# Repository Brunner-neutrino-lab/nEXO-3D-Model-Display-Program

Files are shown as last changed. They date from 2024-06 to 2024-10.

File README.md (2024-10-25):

# nEXO 3D Model and Display

## Overview

This project showcases a scaled-down, 3D-printed model of the nEXO detector, designed to visualize various data related to muon interactions and double beta decay events. The model is created using SolidWorks and powered by a Raspberry Pi, enabling interactive LED displays and simulated data visualization. This project aims to present condensed data from ten years of observation, highlighting the rarity of neutrino-less double beta decay.

## Table of Contents

1. [Introduction](#introduction)
2. [Project Features](#project-features)
3. [Responsibilities](#responsibilities)
4. [Hardware Components](#hardware-components)
5. [Software Components](#software-components)
6. [Setup and Installation](#setup-and-installation)
7. [Data Simulation](#data-simulation)
8. [Usage](#usage)
9. [Acknowledgments](#acknowledgments)

## Introduction

The nEXO detector is part of an experiment projected to detect neutrino-less double beta decay. Our project involves creating a scaled-down 3D model of the detector to visualize simulated muon data and rare decay events in an engaging and informative manner.

## Project Features

- **True-to-Scale 3D Model**: Created in SolidWorks, scaled down by a factor of 100, and optimized for 3D printing.
- **Simulated Data Visualization**:
  - Muons passing through the TPC (Time Projection Chamber).
  - Muons passing through the outer detector.
  - Coincident muons passing through both the TPC and outer detector.
  - Background Region of Interest (ROI) data.
  - Xenon 137 data.
  - Estimated rate of neutrino-less double beta decay.
- **Interactive LED Display**: Powered by a Raspberry Pi, the LED display will showcase multiple half-lives of the decay to highlight its rarity.
- **Condensed Time Frame**: Displaying ten years or five years of data in a two-minute or one-minute visualization respectively.

## Responsibilities

1. 3D model and printing
- Grace, Felix
2. Hardware
- Julien, Felix 
3. Programming
- Sophie, Emilio, Eliot

Brian is advising the programming and hardware

## Hardware Components

- Raspberry Pi (User: pi,  Pass: Element54$)
- 3D-printed model of the nEXO detector (32 components)
- LEDs (5 blue for walls and 4 blue for floor, RGB for TPC)
- Power supply
- Current-limiting resistors
- IC (transistors)
- HAT for raspberry pi
- Wires (mainly used 26AWG)
- Glue
- Mirror sheet

## Software Components

- SolidWorks for 3D modeling
- Python for controlling the Raspberry Pi and LEDs
- Data from previous simulation scripts for muon and decay events

## Setup and Installation

1. **3D Printing**:
   - Use the SolidWorks files provided in the [sharepoint](https://mcgill.sharepoint.com/:f:/s/BrunnerNeutrinoLabModels_Group/EvGFXZofQUZPt6qD_oMlr6YBIfcuM76ZlL9AQwnTyHu-Tg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) to print the scaled-down model of the nEXO detector.
   
2. **Hardware Assembly**:
   - Schematics for the Raspberry Pi HAT and inside the model are found in the 'Schematics' folder.
   - Full tutorial on how to asssemble your own HAT found in 'nEXO Scale Model HAT text.docx'

4. **Software Installation**:
  - Assignment of GPIO pins for LEDS:
      - wallGPIO = 17 #physical/board pin 11
      - floorGPIO = 27 #physical/board pin 13
      - redGPIO = 9 #physical/board pin 21
      - greenGPIO = 11 #physical/board pin 23
      - blueGPIO = 25 #physical/board pin 22
  - The program to display the LEDs is found in the file 'LED_program.py'
  - 'Test.py' was only used to store the RGB values for the TPC colours.
      - in the 'Schematic' folder the LED colour assignment to events is found.

## Data Simulation
General approach: calculate the mean/expected time between events (for our time scale of 2 min = 10 years), then randomly sample the time between LED flashes using an exponential distribution (distribution for time between Poisson events). We have the option
 to vary the half-life of 0vbb as well as the LXe volume (inner 2t or inner 1t). 

The TPC will be flashed different colours for 5 different events in the ROI (the ROI is SS events, with energy within 0vbb FHWM): 
  - 0vbb
  - 2vbb
  - solar v
  - Xe-137 activations
  - and the remaining background events. 

0vbb: Mean number of decays per year is calculated based on the mean lifetime (half-life divided by log(2)), assuming 76.1% of events are in the ROI (as FHWM is approximately 76.1% of area under Gaussian distribution). 

  - 3 sigma discovery potential half-life: 7.4 x 10^27 years (https://iopscience.iop.org/article/10.1088/1361-6471/ac3631/pdf)   
  - Half-life sensitivity: 1.35 × 10^28 years
  - Our third option is currently 1 x 10^27 years.

Total background rate (https://arxiv.org/abs/1805.11142v2, table 3.1):  
  - Inner 2 tons: 3.6 × 10^−4 events/(FWHM·kg·yr)  
  - Inner 1 ton: 1.4 × 10^−4 events/(FWHM·kg·yr)  

Events in the background are separated into 2vbb, solar v, Xe-137 and remaining background according to the composition within FWHM for the inner 2t (https://iopscience.iop.org/article/10.1088/1361-6471/ac3631/pdf, estimated from Fig. 8):  
  - 2vbb: 0.8%  
  - Solar v: 2.1%  
  - Xe-137: 2.4%   
  - Rest of background: 94.7%  

The outer detector (walls and floor) will be flashed for muons (these rates may have to be scaled differently as they are very high with our time scale; currently the lights just stay on):  
  - Muons through TPC: about 0.6 per day 
  - Muons through outer cryostat: about 5 per day 

## Usage

1. **Start the Visualization**:
   - Run the main control script: GUI_program_with_LEDs.py
   - GUI will allow the user to choose options before running simulation

2. **Interacting with the Model**:
   - The LEDs will display different data sets including muons, 2vbb, 0vbb, ROI background data, and Xenon 137 data.
   - There will be an option to view the data from the inner 1 tonne as well as the inner 2 tonne of the detector.
   - Observe the visualization of the estimated rate of neutrino-less double beta decay and its half-lives.
3. **Connecting over SSH**
   - pi must be connected to the same network as device (ethernet/internet)
   - type into terminal 'ssh pi@[pi IP address]'
   - if displaying on touchscreeen you have to define the display enviroment (the screen is just DISPLAY=:0) before the command
     - ex. DISPLAY=:0 gui.py
     - ex. sudo DISPLAY=:0 LEDs.py

## Acknowledgments

This project is developed for the nEXO collaboration's Director's Review.
For questions contact Grace at grace.champagne@mail.mcgill.ca

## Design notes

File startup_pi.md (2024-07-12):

## How to start the pi!

1. Make sure the VGA cable is connectly to the model and the pi
2. Plug in the power supply the the female connector on the pi box
3. The program should startup at boot and now is ready to simulate!
* (the first simulation may not turn on LEDs, just wait for the timer to count down then start again)
* Also the command window can be dragged around screen

## To shut down

1. Press the RaspberryPi symbol in the top left corner and select logout
2. A window should pop up, select shutdown
3. Wait for the green light to fully shut off then unplug (this protects the SD card)

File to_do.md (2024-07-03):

# To Do List

### 3D Modeling

| Task | Person/Area | Deadline | Status | Notes|
|---|---|---|---|---|
| water tank and platform body | Grace |  |✅ Completed  |need to clean up stringing in truss a bit|
|  cryostat | Grace |  |✅ Completed | need to update  |
| platform roof and tank roof| Sophie |  | ✅ Completed | |
| gantry and stairs on roof | Sophie | | ✅ Completed |  |
| cryopit | Julien| | ✅ Completed | going to remodel with the 3D scans of the pit |
| cave and cryopit base | Felix | | ✅ Completed | |
| added connections between different pieces and channels through walls and in base for wiring | Felix | | ✅ Completed |  |
| added channels in floor and access from bottom of base and added ladders to platform| Grace| | ✅ Completed |  |
| new cryostat | | June 28, 2024  |✅ Completed | only need to change supporting structure not TPC or spheres|
| cages for ladders | | | ⬜️ Incomplete | should try with soluable filament |
| rpi case | Felix  |  |✅ Completed | added a VGA connector hole, added room for HAT, need to add screw terminals to connect screw in distribution terminal onto roof |
| cryopit bottom | | |✅ Completed  | make hole larger to fit screw in terminal and re add hole for platform body and added a way to remove terminal and fixed more things |

### Prints (for first model)

| Task | Deadline | Status | Print Time| Notes|
|---|---|---|---|---|
| tank body | | ✅ Completed | 14h|  |
| tank roof and floor |  | ✅ Completed | 3h |  |
| cryostat frame | |✅ Completed | 1h | got to print with no stringing (slower speed + dried filament |
| TPC cover |  |✅ Completed  | 15 min | |
| TPC | |  ✅ Completed | | |
| platform and walkway | | ✅ Completed | 6h| glued on walkway|
| platform roof | | ✅ Completed | 2h |  |
| ladders | June 28, 2024 | ✅ Completed  |  30min | slow down the print speed and decrease layer thickness |
| ladder cages | June 28, 2024 | ⬜️ Incomplete |  | try with soluable |
| gantry crane and boxes | | ✅ Completed | 1h |  |
| cave body | June 26, 2024 |✅ Completed  |  24h | |
| cave dome | June 28, 2024 | ✅ Completed | 14h  | |
| cryopit base | June 28, 2024 | ✅ Completed|  15h| the bottom didn't print correctly may have to reprint |
| cryostat shells | June 26, 2024 | ✅ Completed| 1h  | |
| cryostat supports |  June 28, 2024 | 🔄 In Progress | | for some reason not printing well even though have printed before |
| rpi case | June 28, 2024  |✅ Completed| | |

### Hardware and Software

| Task | Person/Area | Deadline | Status | Notes |
|---|---|---|---|---|
| make plan for videos | Grace + Hannah |  | ✅ Completed  | |
| filming video | Grace + Hannah | June 26, 2024 | 🔄 In Progress | |
| make schematic for HAT |Julien, Grace |  | ✅ Completed | |
| test LEDs with pi | Sophie, Julien | | ✅ Completed | |
| design HAT |  Julien | June 28, 2024 | ✅ Completed | |
| solder first HAT | | June 28, 2024 | ✅ Completed  | |
| test HAT | | |  ✅ Completed | works! however, VGA cable has connected pins so looking for new cable|
| write test code for LEDs | Sophie |  |  ✅ Completed | |
| sand down tank interier and glue reflective foil | Grace | July 4, 2024 |  ✅ Completed |  |
| write GUI for touchscreen | Emilio + Eliot | June 28, 2024 | 🔄 In Progress | try to include option to play video |
| glue screw in terminal onto cryopit base panel |  |  |⬜️ Incomplete |  |
| glue wires and LEDs into place |  |  |  ✅ Completed |  |
| test GUI | |  | ⬜️ Incomplete|  |
| test entire code |  |  | ⬜️ Incomplete |  |

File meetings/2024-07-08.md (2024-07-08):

# Meeting 3

### LIGHTS ON MODEL WORK!

## 3D Model
- all prints completed except one roof tile
- half of the model glued in
- all wiring glued in

### Next steps
- finish final print
- continue gluing rest of model
- secure in screw terminal
- print and assemble 2 more models
  - may need some extra help
- add final items to procurement
- make small beam

## Software
- program completed

### Next steps
- test touchscreen program on pi
- comments on touchscreen screen

## Hardware
- 2/4 HATs completed

### Next steps
- continue third and fourth HAT

## Plan for Video
- almost everything filmed: just need to film final model working

## To Do
- send pics and videos

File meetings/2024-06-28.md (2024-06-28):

# Meeting 3

## 3D Model
- outer cave printed
- printing dome
- added cap to put in the screw terminal for VGA cable
- case for raspberry pi printed
- glued all LEDs into windows and wires on wall and floor
- glued platform and plates together
- paint the lights

### Next steps
- glueing reflective coating
- printing cryostat
- tpc today, tpc cover
- print extra rectangle
- extra pieces: just in case pieces break

## Software
- sophie wrote test code to choose LED colours and for LEDs to flash
- eliot wrote code to add halflives ad the inner 1t and 2t
- issue: when switching between halflives and which volume you want it causes issues due to while true loop
  - maybe add time limit or just stop code
- added GUI to display the colour assignments and options to toggle half lives and volume
- look into displaying a video
- look into other time scales for the muons

### Next steps
- add to git

## Hardware
- soldered 2/3 HATs (tested and circuit works!)
- issue: VGA cable is not 1 to 1

### Next steps
- either make a new VGA cable or order a custom 1 to 1 cable

## Plan for Video
- filming today!!!
- quick explanation of what nEXO is and showcasing the model
- filming group members doing different tasks
- sub teams should write a script saying quick overview of what you did and how it contributes to the model
  - add in the scientific importance
- tentative deadline to film: July 9

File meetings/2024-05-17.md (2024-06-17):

# nEXO Model Meeting 2

### Updates:
**3D model:**
- Completed
  - Connections implemented between components
  - Channels created for LED wiring
  - Added walkway supports around platform structure
  - Printed a prototype base - tank and floor of tank fit in almost perfectly
  - added channels up the walls for LED wires
- In progress
  - modelling the cave in solidworks
  - prints - have printed cryostat (minus clear TPC), tank floor, outer platform body
- Next steps
  - print water tank, tank floor, cave, cryostat frame, roof, walkway

**Hardware:**
- Completed
  - Decided on LEDs - same colour for walls and floor [https://www.digikey.com/en/products/detail/adafruit-industries-llc/5490/16630594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]
- In progress
  - Designing the HAT - rough plan completed
  - Screenshot 2024-06-16 at 3 19 56 PM
  - calculting resistor values for LEDs
     - wall and floor LEDs will have same value

- Next steps
  - Printing HAT and soldering components
  - Testing LEDs with Pi - we only tested them with the 3.3V pin
 
**Program:**
- Completed
  - Assigned pins to LEDs (See README.md)
- In Progress
  - have looked at event rates, some events like muons are very common whereas others like Xe 137 are very very rare
  - we will test these real times and if they are not great we will see
  - writing code for rpi to control LEDs
- Next steps
  - writing PWM program to control the intensity of light and change colours in RGB
  - send out email with event rates to circulate for comments

### Discussion:
- going to use VGA 15 pin connector now instead of bulky d sub
- making prototype of circuit

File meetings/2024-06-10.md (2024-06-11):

# First nEXO 3D model meeting:

### Plan: create a mini model of nExo that can be printed
includes water tank, platform, cryopit, cyostat
LED in walls and in TPC that flash with expected rates of data
almost all solidworks files have been completed
water tank printed in shiny filament for stainless steel
bought soluble filament to print platform with, some troubleshooting with the soluble
blue liht in outer detector when muon passes - only coincident event
TPC red for bg event
green for 2nbb
purple for 0nbb assuming 7.4x10^27 year half life

### Next steps:
- connections bw pieces to fit in each other
- testing soluble filament
- add holes for wiring
- test id small pcb is needed, wiring plan
- acquire and simulate data, put it into a ras pi
- aim to have the project finished by the first week of july

### Questions:
- how much real time should correspond to a day of nEXO data taking??? (2min??)
- other events we want to show?
- use SLAC git for ras pi programming
- show a version with increased rates of 0nbb since it is low
- could have a function switch with an interactive touch screen to change the probablities

## Discussion:
#### Notes:
- updated CAD bc skirt is out of nickel now (no longer electro form copper) (verify with who?) - verified
- Brian might take more of an advisory role for ras pi programming
- for multi-colour LED, might want to find other LEDs, soldering 4 wires to the SMDs might be tough
- circuit can be external, the LEDs will require a driver
- probably need a pcb to deal with all the LEDs
- make a SLAC in nEXO,
- first look at how soldering to the LEDs go, Brian will look at other LEDs
- Look-up table easy, less fun, might be interesting to go with a RNG
- Looking for a generic hat, might not need a custom pcb
#### Roles:
- Sophie will take lead with programming the pi, with Emilio, Kavin to help
- Tania and Felix will check the LEDs and work with the hardware
- Julien will look into the circuit design on kicad and build/look for the hat/pcb
- Grace and felix will continue with the CAD files
- Eliot help with printing
#### To do:
- Use McGill's git, invite Brian
- Regan and Soud offered to help getting the data
- Looking to keep this meeting time

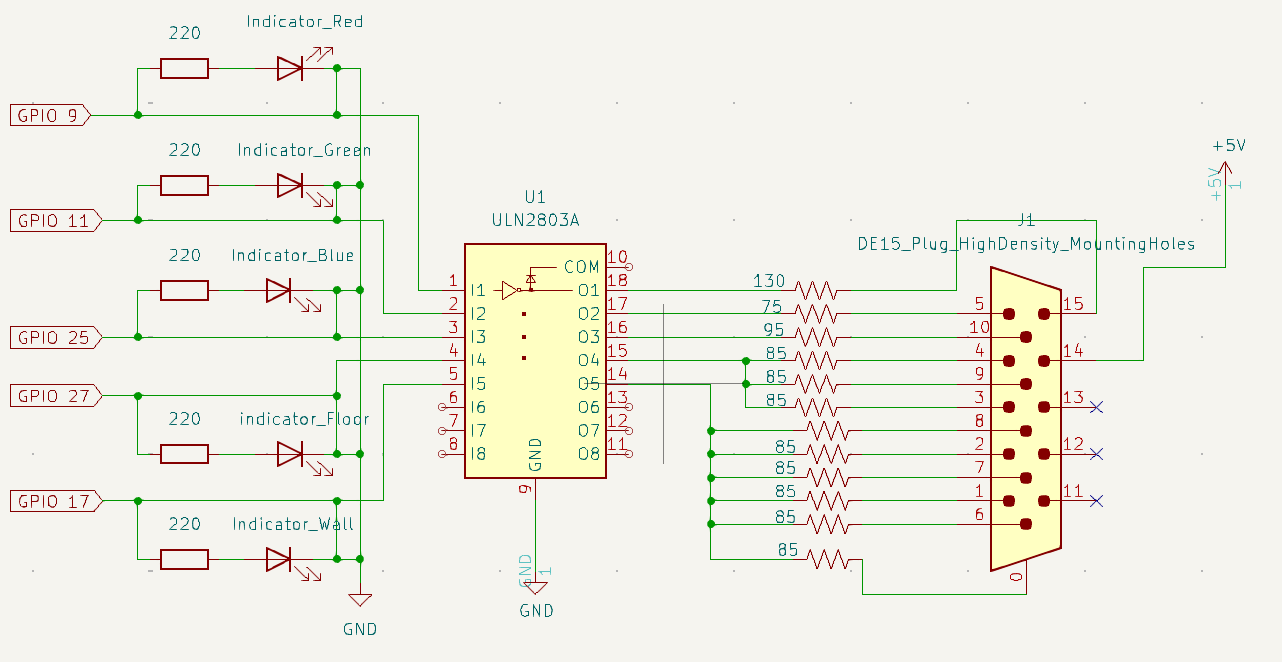
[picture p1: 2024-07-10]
kicad schematic/HAT circuit.png

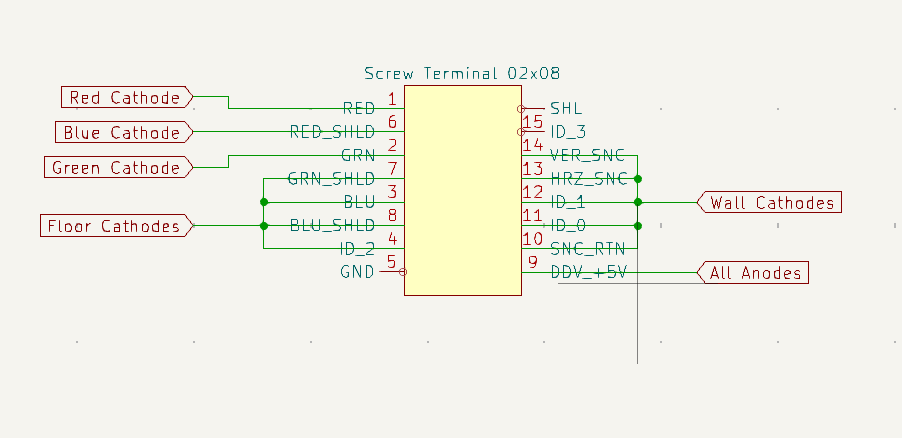
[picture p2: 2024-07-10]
kicad schematic/Screw terminal pinout.png

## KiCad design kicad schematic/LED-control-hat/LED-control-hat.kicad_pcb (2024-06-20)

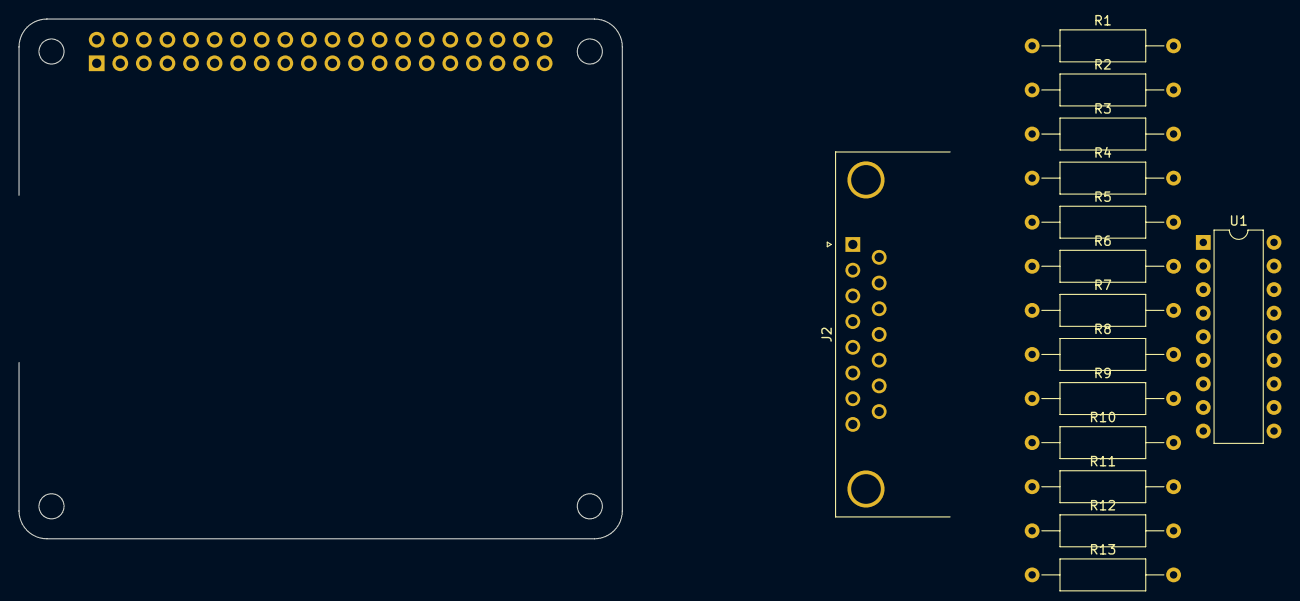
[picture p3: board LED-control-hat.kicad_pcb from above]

Board: 2 copper layers, 65.0 x 56.0 mm, 20 parts (1 on the bottom side), 26 nets, no tracks yet.

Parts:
J1: GPIO; PinSocket_2x20_P2.54mm_Vertical
J2: DA15_Receptacle; DSUB-15_Female_Horizontal_P2.77x2.84mm_EdgePinOffset7.70mm_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
MH1, MH2, MH3, MH4: MountingHole_2.7mm_M2.5
R1, R2, R3, R4, R5, R6, R7, R8, R9, R10, R11, R12, R13: R_US; R_Axial_DIN0309_L9.0mm_D3.2mm_P15.24mm_Horizontal
U1: ULN2803A; DIP-18_W7.62mm

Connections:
+3V3: J1.1, J1.17
+5V: J1.2, J1.4, J2.1
/GPIO17: J1.11, U1.1 (I1)
/GPIO22: J1.15, U1.2 (I2)
/GPIO23: J1.16, U1.3 (I3)
/GPIO24: J1.18, U1.4 (I4)
/GPIO25: J1.22, U1.5 (I5)
GND: J1.6, J1.9, J1.14, J1.20, J1.25, J1.30, J1.34, J1.39, U1.9 (GND)
unnamed: J2.9, R1.2
unnamed: J2.10, R3.2
unnamed: J2.12, R7.2
unnamed: J2.13, R9.2
unnamed: J2.14, R11.2
unnamed: J2.15, R13.2
unnamed: J2.11 (P111), R5.2
unnamed: J2.2, R2.2
unnamed: J2.3, R4.2
unnamed: J2.4, R6.2
unnamed: J2.5, R8.2
unnamed: J2.6, R10.2
unnamed: J2.7, R12.2
unnamed: R1.1, U1.18 (O1)
unnamed: R2.1, U1.17 (O2)
unnamed: R3.1, U1.16 (O3)
unnamed: R4.1, R5.1, R6.1, R7.1, R8.1, U1.15 (O4)
unnamed: R9.1, R10.1, R11.1, R12.1, R13.1, U1.14 (O5)

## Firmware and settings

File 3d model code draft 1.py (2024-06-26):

import RPi.GPIO as GPIO # Import Raspberry Pi GPIO library
import time
import numpy as np
from numpy.random import exponential #for exponential distribution (distribution of distance between events in Poisson process)


# LED setup: wall/floor for outer detector, RGB for colours in TPC

wallGPIO = 17 #physical/board pin 11
floorGPIO = 27 #physical/board pin 13
redGPIO = 9 #physical/board pin 21
greenGPIO = 11 #physical/board pin 23
blueGPIO = 25 #physical/board pin 22

GPIO.setmode(GPIO.BCM)
GPIO.setup(wallGPIO, GPIO.OUT, initial=GPIO.LOW)
GPIO.setup(floorGPIO, GPIO.OUT, initial=GPIO.LOW)
GPIO.setup(redGPIO, GPIO.OUT, initial=GPIO.LOW)
GPIO.setup(greenGPIO, GPIO.OUT, initial=GPIO.LOW)
GPIO.setup(blueGPIO, GPIO.OUT, initial=GPIO.LOW)

RED = GPIO.PWM(redGPIO,100)
GREEN = GPIO.PWM(greenGPIO,100)
BLUE = GPIO.PWM(blueGPIO,100)

RED.start(0)
GREEN.start(0)
BLUE.start(0)


def flash(events): #run this every time an LED flashes. 
    
    flashtime = 0.5 #s that LEDs should flash

    #turn LEDs on
    for event in events:
        if event == "ROI_background": 
            RED.ChangeDutyCycle(0)
            GREEN.ChangeDutyCycle(240/255 * 100)
            BLUE.ChangeDutyCycle(40/255 * 100)
            print("ROI_background on")
        if event == "0vbb":
            RED.ChangeDutyCycle(255/255 * 100)
            GREEN.ChangeDutyCycle(69/255 * 100)
            BLUE.ChangeDutyCycle(0) 
            print("0vbb on")
        if event == "2vbb": 
            RED.ChangeDutyCycle(255/255 * 100)
            GREEN.ChangeDutyCycle(20/255 * 100)
            BLUE.ChangeDutyCycle(147/255 * 100)   
            print("2vbb on")
        if event == "Xe137": 
            RED.ChangeDutyCycle(200/255 * 100)
            GREEN.ChangeDutyCycle(200/255 * 100)
            BLUE.ChangeDutyCycle(200/255 * 100)  
            print("Xe137 on")
        if event == "solar v": 
            RED.ChangeDutyCycle(245/255 * 100)
            GREEN.ChangeDutyCycle(235/255 * 100)
            BLUE.ChangeDutyCycle(10/255 * 100)   
            print("solar v on")
        if event == "TPC_muon": # turn on bottom of outer detector
            GPIO.output(floorGPIO, GPIO.HIGH)
            print("TPC_muon on")
        if event == "cryostat_muon": # turn on whole outer detector
            GPIO.output(floorGPIO, GPIO.HIGH)
            GPIO.output(wallGPIO, GPIO.HIGH)
            print("cryostat muon on")
    
    time.sleep(flashtime)

    #turn LEDs off
    RED.ChangeDutyCycle(0)
    GREEN.ChangeDutyCycle(0)
    BLUE.ChangeDutyCycle(0)
    GPIO.output(floorGPIO, GPIO.LOW)
    GPIO.output(wallGPIO, GPIO.LOW)

def event_rates(half_life:int=0, inner_vol:int=0): #change 0vbb half-life, inner volume to consider
    rates_per_year = np.zeros(7) #array to store events/year for each type
    #event_types = ["0vbb", "2vbb", "Xe 137", "solar v", "ROI background", "TPC muon", "cryostat muon"]


    # 0vbb: 
    #ROI: energy range of 0vbb FWHM, inner 2t of xenon
    #FWHM is approx. 76.1% of area under Gaussian

    Xe_mass = 0.1*133.9053945 + 0.9*135.407219 #in g/mol; for 90% Xe 136, 10% Xe 134
    if inner_vol == 1: #1 ton inner volume
        n_xenon = 10**6 / Xe_mass * 6.022*10**23
    else: #default inner volume is 2 tons
        n_xenon = 2 * 10**6 / Xe_mass * 6.022*10**23 #2 tons * 10^6 g/tons
    
    if half_life == 1: #shorter half-life
        half_life = 1 * 10**27 #years
    elif half_life == 2: #half-life sensitivity
        half_life = 1.35 * 10**28
    else: #deault to 3 sigma discovery potential half-life
        half_life = 7.4 * 10**27 
    
    mean_lifetime = half_life/np.log(2)  #years
    mean_decays = n_xenon/mean_lifetime # particles/year
    mean_decays_ROI = mean_decays * 0.761 #events in ROI
    rates_per_year[0] = mean_decays_ROI


    # background
    if inner_vol == 1: #inner 1t
        total_bgd = 1.4 * 10**-4 #events/(FHWM kg yr)
    else: #default to inner 2t
        total_bgd = 3.6 * 10**-4 #events/(FHWM kg yr)
    bgd_rate = total_bgd * 2 * 10**3 #events/yr
    rate_2vbb = bgd_rate * 0.008 #2vbb is about 0.8% of background
    rate_solar_v = bgd_rate * 0.021 #solar neutrino is roughly 2.1% of background
    rate_Xe137 = bgd_rate * 0.024 #xe 137 is about 2.4% of background
    bgd_remaining = bgd_rate * 0.947
    rates_per_year[1] = rate_2vbb
    rates_per_year[2] = rate_Xe137
    rates_per_year[3] = rate_solar_v
    rates_per_year[4] = bgd_remaining

    # muon through TPC
    mean = 0.6 * 365.25  #muons/year (0.6/day)
    rates_per_year[5] = mean

    # muon through cryostat
    mean = 5 * 365.25 #muons/year (5/day)
    rates_per_year[6] = mean

    # time scale: 2 min = 10 years, so 1 year = 12 seconds
    # events/year * 1 year/12 seconds = events/second. take reciprocal for seconds/event
    # seconds/event is expected (mean) time between successive events
    mean_times = 1/(rates_per_year/12)
    return mean_times
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

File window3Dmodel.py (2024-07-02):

import tkinter as tk

def print_selection():
    print("selection_half_life =", selection_half_life.get(), "selection_volume =", selection_volume.get())
    
root = tk.Tk()
root.title("Test")

main_frame = tk.Frame(root)
main_frame.pack(padx=20, pady=20, fill=tk.BOTH, expand=True)

cases = [
    ("Muons", "blue"),
    ("Xe137", "white"),
    ("0vbb", "orange"),
    ("2vbb", "purple"),
    ("Background", "cyan"),
    ("Solar v", "yellow"),
]

selection_half_life = tk.IntVar()
selection_volume = tk.IntVar()

table_frame = tk.Frame(main_frame)
table_frame.pack(side=tk.LEFT, padx=20, pady=20)

tk.Label(table_frame, text="Color Coding", font=('Arial', 16, 'bold')).grid(row=0, columnspan=2, pady=10)

for i, (case, color) in enumerate(cases, start=1):
    tk.Label(table_frame, text=case, font=('Arial', 12)).grid(row=i, column=0, padx=5, pady=5, sticky='w')
    color_label = tk.Label(table_frame, text=color, font=('Arial', 12), bg=color, fg='black', width=10)
    color_label.grid(row=i, column=1, padx=5, pady=5, sticky='w')

choices_frame = tk.Frame(main_frame)
choices_frame.pack(side=tk.RIGHT, padx=20)

checkbox_frame = tk.Frame(choices_frame)
checkbox_frame.pack(pady=10)

tk.Label(checkbox_frame, text="Choose Half Life:", font=('Arial', 14, 'bold')).pack(pady=5)

checkbox1 = tk.Radiobutton(checkbox_frame, text="Half Life 1", variable=selection_half_life, value=1, font=('Arial', 12))
checkbox1.pack(anchor='w')
checkbox2 = tk.Radiobutton(checkbox_frame, text="Half Life 2", variable=selection_half_life, value=2, font=('Arial', 12))
checkbox2.pack(anchor='w')
checkbox3 = tk.Radiobutton(checkbox_frame, text="Half Life 3", variable=selection_half_life, value=3, font=('Arial', 12))
checkbox3.pack(anchor='w')

volume_frame = tk.Frame(choices_frame)
volume_frame.pack(pady=10)

tk.Label(volume_frame, text="Choose Volume:", font=('Arial', 14, 'bold')).pack(pady=5)

radio1 = tk.Radiobutton(volume_frame, text="1 ton", variable=selection_volume, value=1, font=('Arial', 12))
radio1.pack(anchor='w')
radio2 = tk.Radiobutton(volume_frame, text="2 tons", variable=selection_volume, value=2, font=('Arial', 12))
radio2.pack(anchor='w')

print_button = tk.Button(choices_frame, text="Submit Selections", command=print_selection) #put the function here
print_button.pack(pady=10)

root.mainloop()

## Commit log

2024-06-17 LED draft code
    to test if LED's turn on through GPIO pins with expected resistor values
2024-06-20 kicad
    all kicad files for HAT circuit and inside model connections
    [LED-control-hat.kicad_pcb, LED-control-hat.kicad_sch]
2024-06-20 LED colour assignments
2024-06-26 changes to LED colours
2024-07-08 GUI program with LEDs with comments
2024-07-08 Update GUI program with LEDs.py
2024-07-08 Update GUI program with LEDs.py
    no more tkvideo
2024-07-08 Update GUI program with LEDs.py
    uncommented GPIO parts
2024-07-08 Update GUI program with LEDs.py
    made font smaller
2024-07-10 Create schematic
2024-07-10 Screenshots of Schematic
2024-07-11 Update GUI program with LEDs.py
    stop works?
2024-07-12 Update GUI program with LEDs.py
    added option to stop simulation
2024-11-08 Create test_rgb
    to test the rgb led for red, green and blue
